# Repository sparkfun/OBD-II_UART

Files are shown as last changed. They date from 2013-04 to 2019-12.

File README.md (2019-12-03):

OBD-II UART
===========

<table class="table table-hover table-striped table-bordered">
  <tr align="center">
   <td><a href="https://cdn.sparkfun.com//assets/parts/3/3/1/4/09555-01a.jpg">OBD-II UART</a></td>
   <td><a href="https://www.sparkfun.com/products/10769">SparkFun Car Diagnostics Kit (RTL-10769)</a></td>
  </tr>
  <tr align="center">
    <td><a href="https://www.sparkfun.com/products/9555">OBD-II UART (WIG-09555)</a></td>
    <td><a href="https://www.sparkfun.com/products/10769">SparkFun Car Diagnostics Kit (RTL-10769)</a></td>
  </tr>
</table>

A board that provides a serial interface using the ELM327 command set with a vehicle's OBD-II bus, and supports all major OBD-II standards. 

Repository Contents
-------------------
* **/Firmware** - Example Arduino sketch
* **/Hardware** - All Eagle design files (.brd, .sch)
* **/Software** - Information about desktop program to use with this board. 

Documentation
--------------
* **[Hookup Guide](https://learn.sparkfun.com/tutorials/obd-ii-uart-hookup-guide)** - Basic hookup guide for the OBD-II UART.
* **[Getting Started with OBD-II](https://learn.sparkfun.com/tutorials/getting-started-with-obd-ii)** - A general guide to the OBD-II protocols used for communication in automotive and industrial applications.

Product Versions
----------------
* [WIG-09555](https://www.sparkfun.com/products/9555) - OBD-II UART board
* [RTL-10769](https://www.sparkfun.com/products/10769) - Car Diagnostics Kit Retail, with OBD-II UART and OBD to DB9 cable.

License Information
-------------------
The hardware is released under [Creative Commons Share-alike 3.0](http://creativecommons.org/licenses/by-sa/3.0/).  
All other code is open source so please feel free to do anything you want with it; you buy me a beer if you use this and we meet someday ([Beerware license](http://en.wikipedia.org/wiki/Beerware)).

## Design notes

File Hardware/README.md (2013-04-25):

# What Are these Files?

The .sch and .brd files hare are Eagle CAD schematic and PCB design files.
These files were created with Eagle 6.4.0, you'll need Eagle 6.0 or later to open them up. There is a free, lite, version of Eagle available from [cadsoftusa.com](cadsoftusa.com).

# License

This product is open source! These Eagle files are released under the Creative Commons Share-Alike Attribution license ([CC BY-SA 3.0](http://creativecommons.org/licenses/by-sa/3.0/us/)).

Please use, reuse, and modify these files as you see fit. Please maintain attribution and release anything derivative under the same license.

- Your friends at SparkFun.

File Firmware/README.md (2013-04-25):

OBD-II UART Example Code
-------------------------

This Arduino sketch is designed to print out OBD data over a [Serial-Enabled LCD](https://www.sparkfun.com/products/9393) from an Arduino.

This sketch is written for Arduino 1.0+.

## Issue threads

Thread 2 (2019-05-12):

Directly communicate with can bus?

DeadlyMelqn, 2019-05-12:
The schematic says it uses the mcp2551 for can bus. Is there a way I can directly communicate with the can-bus without having to go through obd2 interface?

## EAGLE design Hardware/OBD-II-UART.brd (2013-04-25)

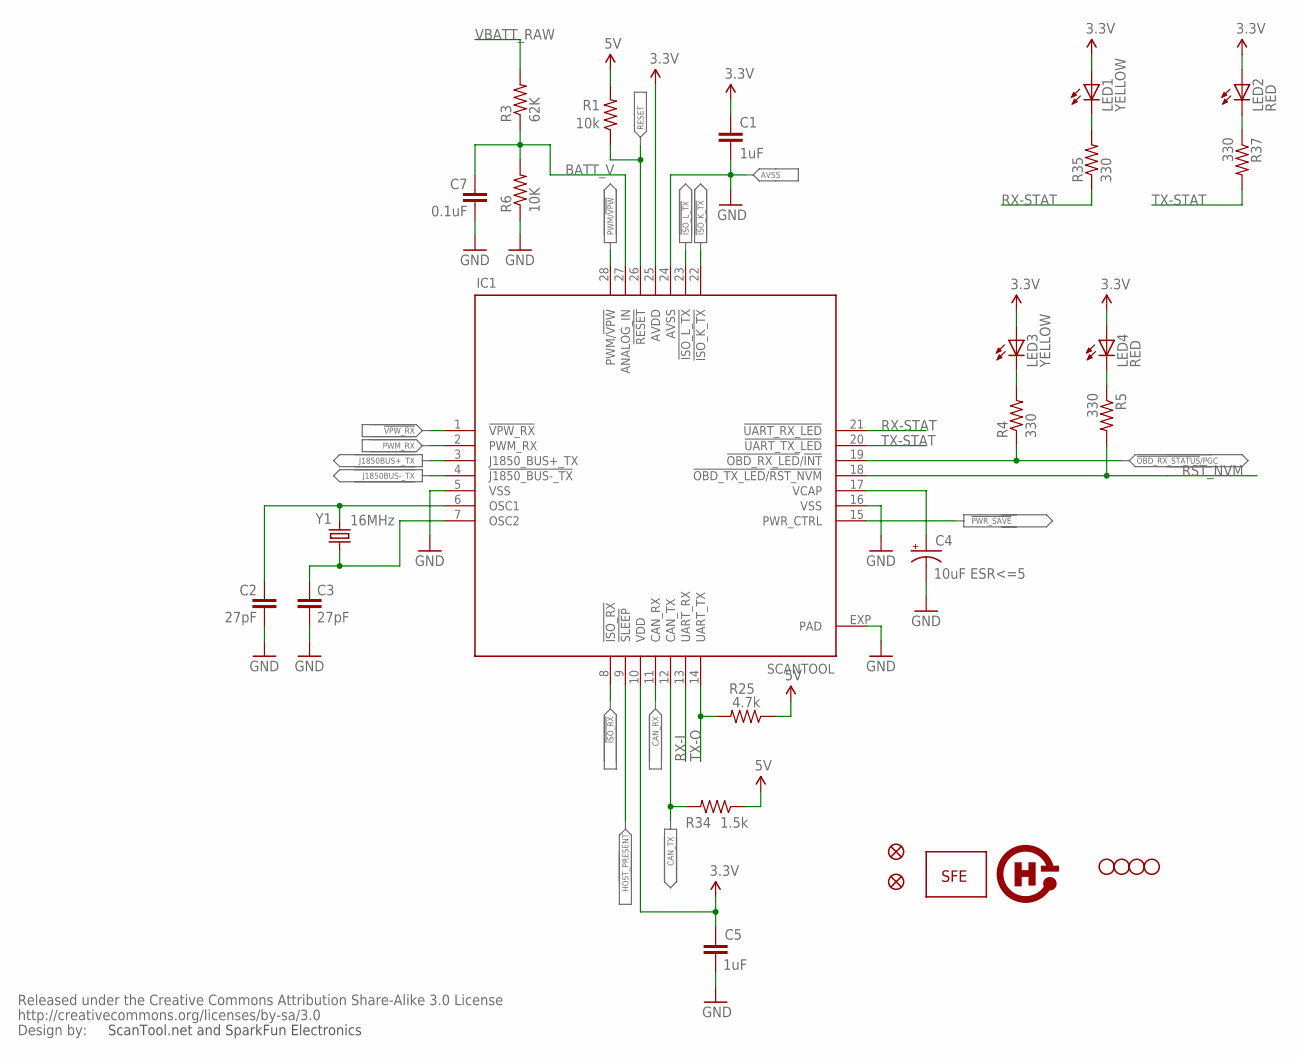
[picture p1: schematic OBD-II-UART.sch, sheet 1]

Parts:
C1, C5: 1uF; 0402-CAP
C2, C3: 27pF; 0402-CAP
C4: 10uF ESR<=5; EIA3216
C7: 0.1uF; 0402-CAP
IC1: SCANTOOL; _STN_SCANTOOL_QFN-28-S
JP2, JP10: FIDUCIAL1X2; FIDUCIAL-1X2
JP3: LOGO-SFENEW; SFE-NEW-WEBLOGO
JP4, JP5, JP6, JP7: STAND-OFF
LED1, LED3: YELLOW; LED-0603
LED2, LED4: RED; LED-0603
R1: 10k; 0402-RES
R3: 62K; 0402-RES
R4, R5, R35, R37: 330; 0402-RES
R6: 10K; 0402-RES
R25: 4.7k; 0402-RES
R34: 1.5k; 0402-RES
U$1: CREATIVE_COMMONS
U$14: OSHW-LOGO
Y1: 16MHz; CRYSTAL-SMD-5X3

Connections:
3.3V: C1.1, C5.1, IC1.10 (VDD), IC1.25 (AVDD), LED1.A, LED2.A, LED3.A, LED4.A; also elsewhere on the board
5V: R1.2, R25.1, R34.1; also elsewhere on the board
!ISO_K_TX: IC1.22 (!ISO_K_TX); also elsewhere on the board
!ISO_L_TX: IC1.23 (!ISO_L_TX); also elsewhere on the board
!ISO_RX: IC1.8 (!ISO_RX); also elsewhere on the board
!OBD_RX_STATUS!/PGC: IC1.19 (!OBD_RX_LED!/!INT), R4.1
!PWR_SAVE: IC1.15 (PWR_CTRL)
!VPW_RX: IC1.1 (!VPW_RX); also elsewhere on the board
BATT_V: C7.1, IC1.27 (ANALOG_IN), R3.1, R6.2
CAN_RX: IC1.11 (CAN_RX); also elsewhere on the board
CAN_TX: IC1.12 (CAN_TX), R34.2; also elsewhere on the board
GND: C1.2, C2.2, C3.2, C4.C (-), C5.2, C7.2, IC1.5 (VSS), IC1.16 (VSS), IC1.24 (AVSS), IC1.EXP (PAD), R6.1; also elsewhere on the board
HOST_PRESENT: IC1.9 (!SLEEP)
J1850BUS+_TX: IC1.3 (J1850_BUS+_TX); also elsewhere on the board
J1850BUS-_TX: IC1.4 (!J1850_BUS-_TX); also elsewhere on the board
unnamed: C4.A (+), IC1.17 (VCAP)
unnamed: LED3.C, R4.2
unnamed: LED4.C, R5.1
unnamed: LED1.C, R35.2
unnamed: LED2.C, R37.1
OSC1: C2.1, IC1.6 (OSC1), Y1.3 (2)
OSC2: C3.1, IC1.7 (OSC2), Y1.1
PWM/!VPW: IC1.28 (PWM/!VPW); also elsewhere on the board
PWM_RX: IC1.2 (PWM_RX); also elsewhere on the board
RESET: IC1.26 (!RESET), R1.1
RST_NVM: IC1.18 (!OBD_TX_LED!/!RST_NVM), R5.2; also elsewhere on the board
RX-I: IC1.13 (UART_RX); also elsewhere on the board
RX-STAT: IC1.21 (!UART_RX_LED), R35.1
TX-O: IC1.14 (UART_TX), R25.2; also elsewhere on the board
TX-STAT: IC1.20 (!UART_TX_LED), R37.2
VBATT_RAW: R3.2; also elsewhere on the board

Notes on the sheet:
AVSS
ScanTool.net and SparkFun Electronics

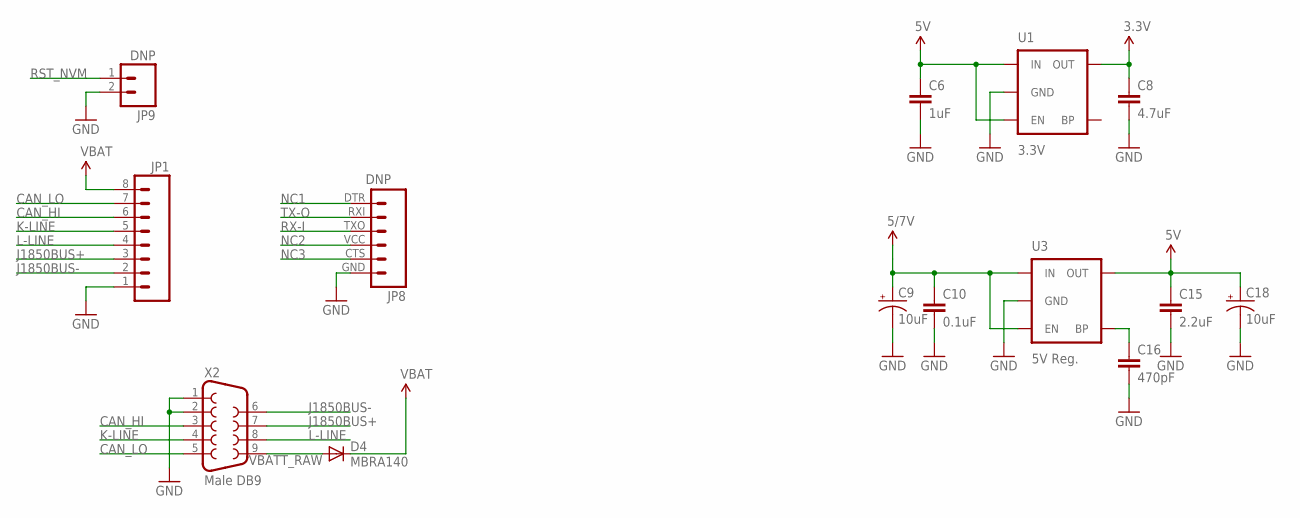
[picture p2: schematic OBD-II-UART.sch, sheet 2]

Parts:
C6: 1uF; 0402-CAP
C8: 4.7uF; 0402-CAP
C9, C18: 10uF; EIA3216
C10: 0.1uF; 0402-CAP
C15: 2.2uF; 0402-CAP
C16: 470pF; 0402-CAP
D4: MBRA140; SMA-DIODE
JP1: M08; 1X08
JP8: DNP; FTDI_BASIC
JP9: DNP; 1X02
U1: 3.3V; SOT23-5
U3: 5V Reg.; SOT23-5
X2: Male DB9; DB9_MALE

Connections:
3.3V: C8.1, U1.5 (OUT); also elsewhere on the board
5V: C6.1, C15.1, C18.A (+), U1.1 (IN), U1.3 (EN), U3.5 (OUT); also elsewhere on the board
CAN_HI: JP1.6, X2.3; also elsewhere on the board
CAN_LO: JP1.7, X2.5; also elsewhere on the board
GND: C6.2, C8.2, C9.C (-), C10.2, C15.2, C16.2, C18.C (-), JP1.1, JP8.GND (6), JP9.2, U1.2 (GND), U3.2 (GND), X2.1, X2.2; also elsewhere on the board
J1850BUS+: JP1.3, X2.7; also elsewhere on the board
J1850BUS-: JP1.2, X2.6; also elsewhere on the board
K-LINE: JP1.5, X2.4; also elsewhere on the board
L-LINE: JP1.4, X2.8; also elsewhere on the board
unnamed: C16.1, U3.4 (BP)
NC1: JP8.DTR (1)
NC2: JP8.VCC (4)
NC3: JP8.CTS (5)
RST_NVM: JP9.1; also elsewhere on the board
RX-I: JP8.TXO (3); also elsewhere on the board
TX-O: JP8.RXI (2); also elsewhere on the board
VBAT: D4.C, JP1.8; also elsewhere on the board
VBATT_RAW: D4.A, X2.9; also elsewhere on the board
VCC: C9.A (+), C10.1, U3.1 (IN), U3.3 (EN); also elsewhere on the board

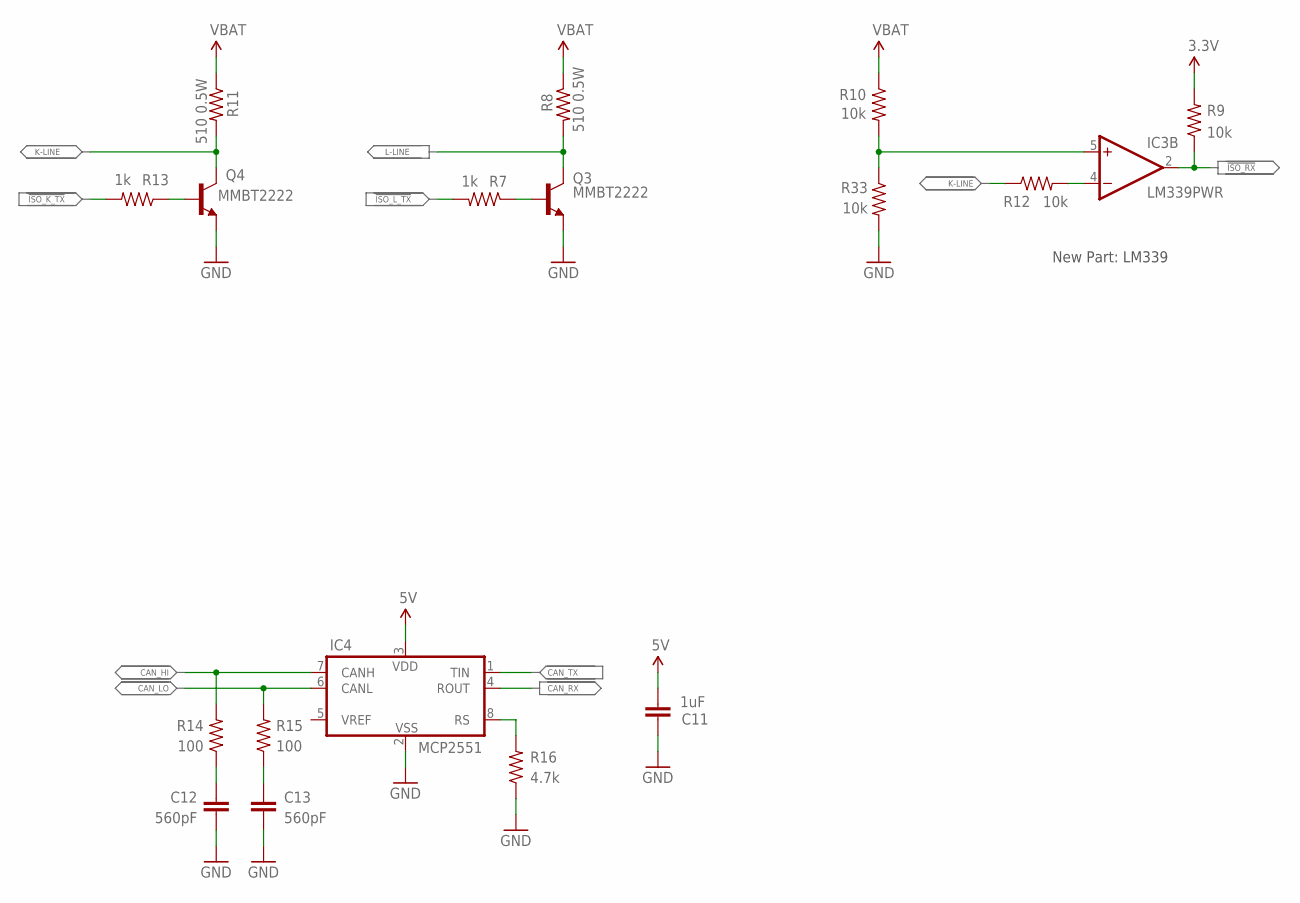
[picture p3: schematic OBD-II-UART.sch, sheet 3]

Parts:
C11: 1uF; 0402-CAP
C12, C13: 560pF; 0402-CAP
IC3: LM339PWR; TSSOP-14
IC4: MCP2551; SO-8
Q3, Q4: MMBT2222; SOT23-3
R7, R13: 1k; 0402-RES
R8, R11: 510 0.5W; 2010
R9, R10, R12, R33: 10k; 0402-RES
R14, R15: 100; 0402-RES
R16: 4.7k; 0402-RES

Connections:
3.3V: R9.2; also elsewhere on the board
5V: C11.1, IC4.3 (VDD); also elsewhere on the board
!ISO_K_TX: R13.2; also elsewhere on the board
!ISO_L_TX: R7.2; also elsewhere on the board
!ISO_RX: IC3.2 (OUT), R9.1; also elsewhere on the board
CAN_HI: IC4.7 (CANH), R14.2; also elsewhere on the board
CAN_LO: IC4.6 (CANL), R15.2; also elsewhere on the board
CAN_RX: IC4.4 (ROUT); also elsewhere on the board
CAN_TX: IC4.1 (TIN); also elsewhere on the board
GND: C11.2, C12.2, C13.2, IC4.2 (VSS), Q3.2 (E), Q4.2 (E), R16.1, R33.2; also elsewhere on the board
K-LINE: Q4.3 (C), R11.2, R12.1; also elsewhere on the board
L-LINE: Q3.3 (C), R8.2; also elsewhere on the board
unnamed: Q4.1 (B), R13.1
unnamed: Q3.1 (B), R7.1
unnamed: IC3.5 (+IN), R10.2, R33.1
unnamed: C12.1, R14.1
unnamed: IC4.8 (RS), R16.2
unnamed: IC3.4 (-IN), R12.2
unnamed: C13.1, R15.1
VBAT: R8.1, R10.1, R11.1; also elsewhere on the board

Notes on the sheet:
New Part: LM339

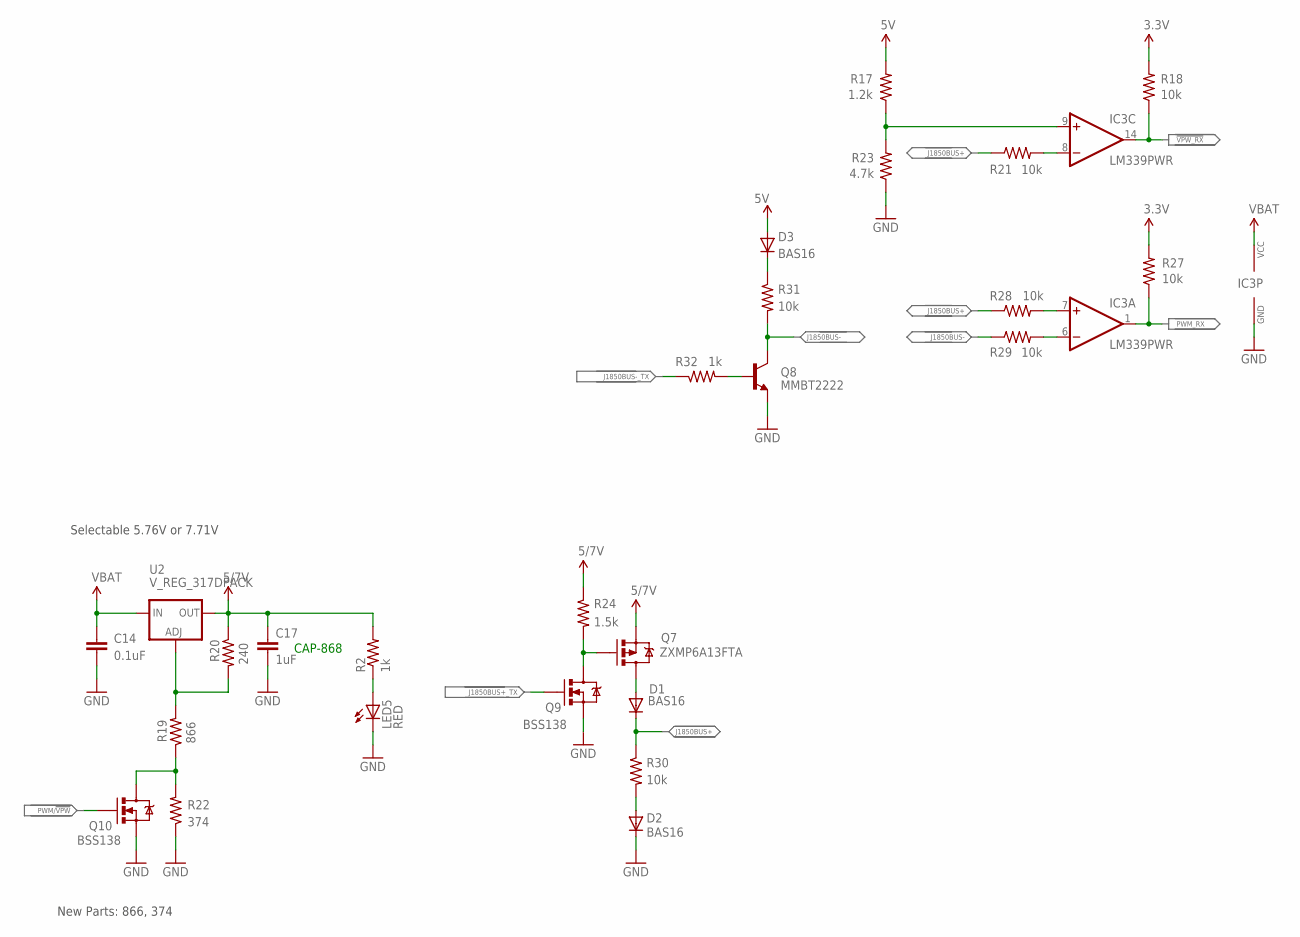
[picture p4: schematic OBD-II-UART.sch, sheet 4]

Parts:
C14: 0.1uF; 0402-CAP
C17: 1uF; 0402-CAP
D1, D2, D3: BAS16; SOD-323
IC3: LM339PWR; TSSOP-14
LED5: RED; LED-0603
Q7: ZXMP6A13FTA; SOT23
Q8: MMBT2222; SOT23-3
Q9, Q10: BSS138; SOT23-3
R2, R32: 1k; 0402-RES
R17: 1.2k; 0402-RES
R18, R21, R27, R28, R29, R30, R31: 10k; 0402-RES
R19: 866; 0402-RES
R20: 240; 0402-RES
R22: 374; 0402-RES
R23: 4.7k; 0402-RES
R24: 1.5k; 0402-RES
U2: V_REG_317DPACK; V-REG_DPACK

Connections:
3.3V: R18.2, R27.2; also elsewhere on the board
5V: D3.2 (A), R17.2; also elsewhere on the board
!VPW_RX: IC3.14 (OUT), R18.1; also elsewhere on the board
GND: C14.2, C17.2, D2.1 (C), IC3.12 (GND), LED5.C, Q8.2 (E), Q9.2 (S), Q10.2 (S), R22.1, R23.1; also elsewhere on the board
J1850BUS+: D1.1 (C), R21.1, R28.1, R30.1; also elsewhere on the board
J1850BUS+_TX: Q9.1 (G); also elsewhere on the board
J1850BUS-: Q8.3 (C), R29.1, R31.2; also elsewhere on the board
J1850BUS-_TX: R32.1; also elsewhere on the board
unnamed: IC3.7 (+IN), R28.2
unnamed: IC3.6 (-IN), R29.2
unnamed: IC3.8 (-IN), R21.2
unnamed: R19.2, R20.2, U2.1 (ADJ)
unnamed: D1.2 (A), Q7.3 (D)
unnamed: IC3.9 (+IN), R17.1, R23.2
unnamed: D3.1 (C), R31.1
unnamed: Q7.1 (G), Q9.3 (D), R24.2
unnamed: Q10.3 (D), R19.1, R22.2
unnamed: D2.2 (A), R30.2
unnamed: Q8.1 (B), R32.2
unnamed: LED5.A, R2.1
PWM/!VPW: Q10.1 (G); also elsewhere on the board
PWM_RX: IC3.1 (OUT), R27.1; also elsewhere on the board
VBAT: C14.1, IC3.3 (VCC), U2.3 (IN); also elsewhere on the board
VCC: C17.1, Q7.2 (S), R2.2, R20.1, R24.1, U2.4 (OUT); also elsewhere on the board

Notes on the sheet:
Selectable 5.76V or 7.71V
New Parts: 866, 374
CAP-868

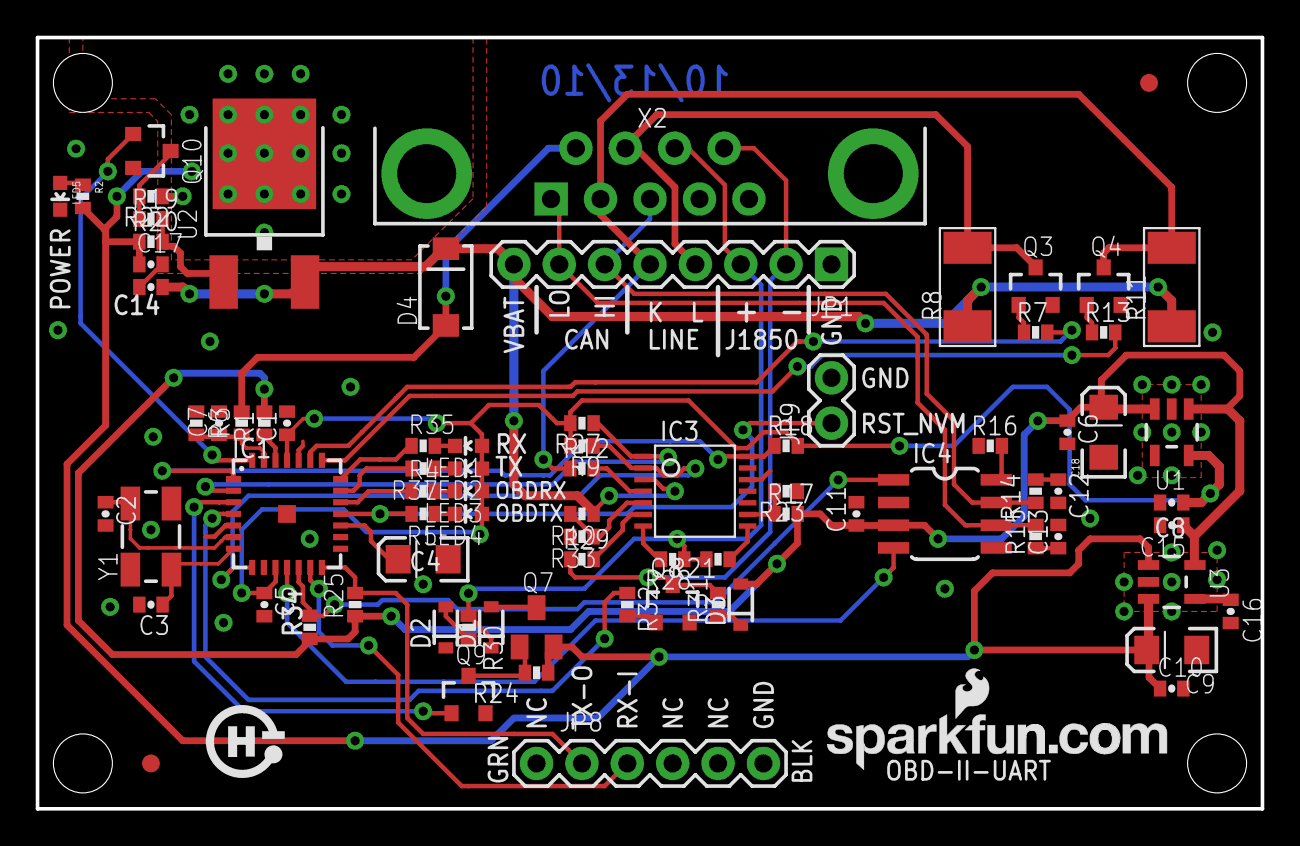
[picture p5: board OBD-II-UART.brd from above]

Board: 2 copper layers, 68.6 x 43.2 mm, 88 parts (0 on the bottom side), 57 nets.

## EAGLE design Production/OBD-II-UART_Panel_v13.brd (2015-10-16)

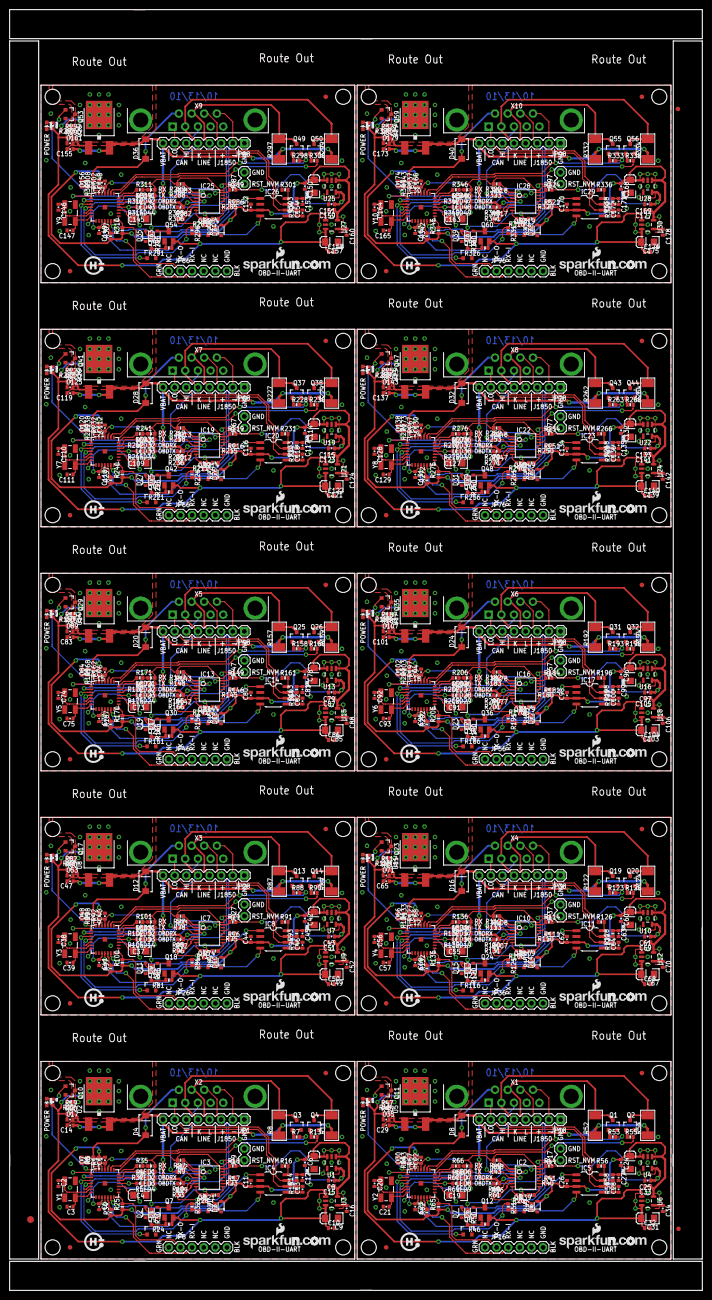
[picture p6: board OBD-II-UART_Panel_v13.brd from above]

Board: 2 copper layers, 151.4 x 279.9 mm, 873 parts (0 on the bottom side), 570 nets.

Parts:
C1, C5, C6, C11, C17, C22, C23, C24, C26, C35, C40, C41, C42, C44, C53, C58, C59, C60, C62, C71, C76, C77, C78, C80, C89, C94, C95, C96, C98, C107, C112, C113, C114, C116, C125, C130, C131, C132, C134, C143, C148, C149, C150, C152, C161, C166, C167, C168, C170, C179: 1uF; 0402-CAP
C2, C3, C20, C21, C38, C39, C56, C57, C74, C75, C92, C93, C110, C111, C128, C129, C146, C147, C164, C165: 27pF; 0402-CAP
C4, C19, C37, C55, C73, C91, C109, C127, C145, C163: 10uF ESR<=5; EIA3216
C7, C10, C14, C29, C30, C32, C47, C48, C50, C65, C66, C68, C83, C84, C86, C101, C102, C104, C119, C120, C122, C137, C138, C140, C155, C156, C158, C173, C174, C176: 0.1uF; 0402-CAP
C8, C25, C43, C61, C79, C97, C115, C133, C151, C169: 4.7uF; 0402-CAP
C9, C18, C31, C36, C49, C54, C67, C72, C85, C90, C103, C108, C121, C126, C139, C144, C157, C162, C175, C180: 10uF; EIA3216
C12, C13, C27, C28, C45, C46, C63, C64, C81, C82, C99, C100, C117, C118, C135, C136, C153, C154, C171, C172: 560pF; 0402-CAP
C15, C33, C51, C69, C87, C105, C123, C141, C159, C177: 2.2uF; 0402-CAP
C16, C34, C52, C70, C88, C106, C124, C142, C160, C178: 470pF; 0402-CAP
D1, D2, D3, D5, D6, D7, D9, D10, D11, D13, D14, D15, D17, D18, D19, D21, D22, D23, D25, D26, D27, D29, D30, D31, D33, D34, D35, D37, D38, D39: BAS16; SOD-323
D4, D8, D12, D16, D20, D24, D28, D32, D36, D40: MBRA140; SMA-DIODE
E$1: FIDUCIAL-1.5X3
E$5, E$8: FIDUCIAL-1X2
IC1, IC6, IC9, IC12, IC15, IC18, IC21, IC24, IC27, IC30: SCANTOOL; _STN_SCANTOOL_QFN-28-S
IC2, IC3, IC7, IC10, IC13, IC16, IC19, IC22, IC25, IC28: LM339PWR; TSSOP-14
IC4, IC5, IC8, IC11, IC14, IC17, IC20, IC23, IC26, IC29: MCP2551; SO-8
JP1, JP18, JP28, JP38, JP48, JP58, JP68, JP78, JP88, JP98: 1X08
JP2, JP10, JP19, JP20, JP29, JP30, JP39, JP40, JP49, JP50, JP59, JP60, JP69, JP70, JP79, JP80, JP89, JP90, JP99, JP100: FIDUCIAL1X2; FIDUCIAL-1X2
JP3, JP11, JP21, JP31, JP41, JP51, JP61, JP71, JP81, JP91: LOGO-SFENEW; SFE-NEW-WEBLOGO
JP4, JP5, JP6, JP7, JP12, JP13, JP14, JP15, JP22, JP23, JP24, JP25, JP32, JP33, JP34, JP35, JP42, JP43, JP44, JP45, JP52, JP53, JP54, JP55, JP62, JP63, JP64, JP65, JP72, JP73, JP74, JP75, JP82, JP83, JP84, JP85, JP92, JP93, JP94, JP95: STAND-OFF
JP8, JP16, JP26, JP36, JP46, JP56, JP66, JP76, JP86, JP96: DNP; FTDI_BASIC
JP9, JP17, JP27, JP37, JP47, JP57, JP67, JP77, JP87, JP97: DNP; 1X02
LED1, LED3, LED6, LED8, LED11, LED13, LED16, LED18, LED21, LED23, LED26, LED28, LED31, LED33, LED36, LED38, LED41, LED43, LED46, LED48: YELLOW; LED-0603
LED2, LED4, LED5, LED7, LED9, LED10, LED12, LED14, LED15, LED17, LED19, LED20, LED22, LED24, LED25, LED27, LED29, LED30, LED32, LED34, LED35, LED37, LED39, LED40, LED42, LED44, LED45, LED47, LED49, LED50: RED; LED-0603
Q1, Q2, Q3, Q4, Q5, Q8, Q13, Q14, Q15, Q19, Q20, Q21, Q25, Q26, Q27, Q31, Q32, Q33, Q37, Q38, Q39, Q43, Q44, Q45, Q49, Q50, Q51, Q55, Q56, Q57: MMBT2222; SOT23-3
Q6, Q9, Q10, Q11, Q16, Q17, Q22, Q23, Q28, Q29, Q34, Q35, Q40, Q41, Q46, Q47, Q52, Q53, Q58, Q59: BSS138; SOT23-3
Q7, Q12, Q18, Q24, Q30, Q36, Q42, Q48, Q54, Q60: ZXMP6A13FTA; SOT23
R1, R9, R10, R12, R18, R21, R26, R27, R28, R29, R30, R31, R33, R36, R38, R39, R42, R43, R44, R49, R50, R57, R60, R61, R71, R72, R73, R74, R77, R78, R79, R84, R85, R92, R95, R96, R106, R107, R108, R109, R112, R113, R114, R119, R120, R127, R130, R131, R141, R142, R143, R144, R147, R148, R149, R154, R155, R162, R165, R166, R176, R177, R178, R179, R182, R183, R184, R189, R190, R197, R200, R201, R211, R212, R213, R214, R217, R218, R219, R224, R225, R232, R235, R236, R246, R247, R248, R249, R252, R253, R254, R259, R260, R267, R270, R271, R281, R282, R283, R284, R287, R288, R289, R294, R295, R302, R305, R306, R316, R317, R318, R319, R322, R323, R324, R329, R330, R337, R340, R341: 10k; 0402-RES
R2, R7, R13, R32, R51, R53, R55, R70, R86, R88, R90, R105, R121, R123, R125, R140, R156, R158, R160, R175, R191, R193, R195, R210, R226, R228, R230, R245, R261, R263, R265, R280, R296, R298, R300, R315, R331, R333, R335, R350: 1k; 0402-RES
R3, R63, R98, R133, R168, R203, R238, R273, R308, R343: 62K; 0402-RES
R4, R5, R35, R37, R66, R67, R68, R69, R101, R102, R103, R104, R136, R137, R138, R139, R171, R172, R173, R174, R206, R207, R208, R209, R241, R242, R243, R244, R276, R277, R278, R279, R311, R312, R313, R314, R346, R347, R348, R349: 330; 0402-RES
R6, R64, R99, R134, R169, R204, R239, R274, R309, R344: 10K; 0402-RES
R8, R11, R52, R54, R87, R89, R122, R124, R157, R159, R192, R194, R227, R229, R262, R264, R297, R299, R332, R334: 510 0.5W; 2010
R14, R15, R58, R59, R93, R94, R128, R129, R163, R164, R198, R199, R233, R234, R268, R269, R303, R304, R338, R339: 100; 0402-RES
R16, R23, R25, R40, R56, R65, R75, R91, R100, R110, R126, R135, R145, R161, R170, R180, R196, R205, R215, R231, R240, R250, R266, R275, R285, R301, R310, R320, R336, R345: 4.7k; 0402-RES
R17, R41, R76, R111, R146, R181, R216, R251, R286, R321: 1.2k; 0402-RES
R19, R47, R82, R117, R152, R187, R222, R257, R292, R327: 866; 0402-RES
R20, R45, R80, R115, R150, R185, R220, R255, R290, R325: 240; 0402-RES
R22, R48, R83, R118, R153, R188, R223, R258, R293, R328: 374; 0402-RES
R24, R34, R46, R62, R81, R97, R116, R132, R151, R167, R186, R202, R221, R237, R256, R272, R291, R307, R326, R342: 1.5k; 0402-RES
U1, U4, U7, U10, U13, U16, U19, U22, U25, U28: 3.3V; SOT23-5
U2, U5, U8, U11, U14, U17, U20, U23, U26, U29: V_REG_317DPACK; V-REG_DPACK
U3, U6, U9, U12, U15, U18, U21, U24, U27, U30: 5V Reg.; SOT23-5
U$1, U$2, U$3, U$4, U$5, U$6, U$7, U$8, U$9, U$14: OSHW-LOGO
X1, X2, X3, X4, X5, X6, X7, X8, X9, X10: Male DB9; DB9_MALE
Y1, Y2, Y3, Y4, Y5, Y6, Y7, Y8, Y9, Y10: 16MHz; CRYSTAL-SMD-5X3

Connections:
3.3V: C1.1, C5.1, C8.1, IC1.10, IC1.25, LED1.A, LED2.A, LED3.A, LED4.A, R9.2, R18.2, R27.2, U1.5
3.3V1: C22.1, C23.1, C25.1, IC6.10, IC6.25, LED6.A, LED7.A, LED8.A, LED9.A, R42.2, R43.2, R44.2, U4.5
3.3V2: C40.1, C41.1, C43.1, IC9.10, IC9.25, LED11.A, LED12.A, LED13.A, LED14.A, R77.2, R78.2, R79.2, U7.5
3.3V3: C58.1, C59.1, C61.1, IC12.10, IC12.25, LED16.A, LED17.A, LED18.A, LED19.A, R112.2, R113.2, R114.2, U10.5
3.3V4: C76.1, C77.1, C79.1, IC15.10, IC15.25, LED21.A, LED22.A, LED23.A, LED24.A, R147.2, R148.2, R149.2, U13.5
3.3V5: C94.1, C95.1, C97.1, IC18.10, IC18.25, LED26.A, LED27.A, LED28.A, LED29.A, R182.2, R183.2, R184.2, U16.5
3.3V6: C112.1, C113.1, C115.1, IC21.10, IC21.25, LED31.A, LED32.A, LED33.A, LED34.A, R217.2, R218.2, R219.2, U19.5
3.3V7: C130.1, C131.1, C133.1, IC24.10, IC24.25, LED36.A, LED37.A, LED38.A, LED39.A, R252.2, R253.2, R254.2, U22.5
3.3V8: C148.1, C149.1, C151.1, IC27.10, IC27.25, LED41.A, LED42.A, LED43.A, LED44.A, R287.2, R288.2, R289.2, U25.5
3.3V9: C166.1, C167.1, C169.1, IC30.10, IC30.25, LED46.A, LED47.A, LED48.A, LED49.A, R322.2, R323.2, R324.2, U28.5
5V: C6.1, C11.1, C15.1, C18.A, D3.2, IC4.3, R1.2, R17.2, R25.1, R34.1, U1.1, U1.3, U3.5
5V1: C24.1, C26.1, C33.1, C36.A, D6.2, IC5.3, R41.2, R57.2, R62.1, R65.1, U4.1, U4.3, U6.5
5V2: C42.1, C44.1, C51.1, C54.A, D10.2, IC8.3, R76.2, R92.2, R97.1, R100.1, U7.1, U7.3, U9.5
5V3: C60.1, C62.1, C69.1, C72.A, D14.2, IC11.3, R111.2, R127.2, R132.1, R135.1, U10.1, U10.3, U12.5
5V4: C78.1, C80.1, C87.1, C90.A, D18.2, IC14.3, R146.2, R162.2, R167.1, R170.1, U13.1, U13.3, U15.5
5V5: C96.1, C98.1, C105.1, C108.A, D22.2, IC17.3, R181.2, R197.2, R202.1, R205.1, U16.1, U16.3, U18.5
5V6: C114.1, C116.1, C123.1, C126.A, D26.2, IC20.3, R216.2, R232.2, R237.1, R240.1, U19.1, U19.3, U21.5
5V7: C132.1, C134.1, C141.1, C144.A, D30.2, IC23.3, R251.2, R267.2, R272.1, R275.1, U22.1, U22.3, U24.5
5V8: C150.1, C152.1, C159.1, C162.A, D34.2, IC26.3, R286.2, R302.2, R307.1, R310.1, U25.1, U25.3, U27.5
5V9: C168.1, C170.1, C177.1, C180.A, D38.2, IC29.3, R321.2, R337.2, R342.1, R345.1, U28.1, U28.3, U30.5
!ISO_K_TX: IC1.22, R13.2
!ISO_K_TX1: IC6.22, R55.2
!ISO_K_TX2: IC9.22, R90.2
!ISO_K_TX3: IC12.22, R125.2
!ISO_K_TX4: IC15.22, R160.2
!ISO_K_TX5: IC18.22, R195.2
!ISO_K_TX6: IC21.22, R230.2
!ISO_K_TX7: IC24.22, R265.2
!ISO_K_TX8: IC27.22, R300.2
!ISO_K_TX9: IC30.22, R335.2
!ISO_L_TX: IC1.23, R7.2
!ISO_L_TX1: IC6.23, R53.2
!ISO_L_TX2: IC9.23, R88.2
!ISO_L_TX3: IC12.23, R123.2
!ISO_L_TX4: IC15.23, R158.2
!ISO_L_TX5: IC18.23, R193.2
!ISO_L_TX6: IC21.23, R228.2
!ISO_L_TX7: IC24.23, R263.2
!ISO_L_TX8: IC27.23, R298.2
!ISO_L_TX9: IC30.23, R333.2
!ISO_RX: IC1.8, IC3.2, R9.1
!ISO_RX1: IC2.2, IC6.8, R43.1
!ISO_RX2: IC7.2, IC9.8, R78.1
!ISO_RX3: IC10.2, IC12.8, R113.1
!ISO_RX4: IC13.2, IC15.8, R148.1
!ISO_RX5: IC16.2, IC18.8, R183.1
!ISO_RX6: IC19.2, IC21.8, R218.1
!ISO_RX7: IC22.2, IC24.8, R253.1
!ISO_RX8: IC25.2, IC27.8, R288.1
!ISO_RX9: IC28.2, IC30.8, R323.1
!OBD_RX_STATUS!/PGC: IC1.19, R4.1
!OBD_RX_STATUS!/PGC1: IC6.19, R68.1
!OBD_RX_STATUS!/PGC2: IC9.19, R103.1
!OBD_RX_STATUS!/PGC3: IC12.19, R138.1
!OBD_RX_STATUS!/PGC4: IC15.19, R173.1
!OBD_RX_STATUS!/PGC5: IC18.19, R208.1
!OBD_RX_STATUS!/PGC6: IC21.19, R243.1
!OBD_RX_STATUS!/PGC7: IC24.19, R278.1
!OBD_RX_STATUS!/PGC8: IC27.19, R313.1
!OBD_RX_STATUS!/PGC9: IC30.19, R348.1
!VPW_RX: IC1.1, IC3.14, R18.1
!VPW_RX1: IC2.14, IC6.1, R44.1
!VPW_RX2: IC7.14, IC9.1, R79.1
!VPW_RX3: IC10.14, IC12.1, R114.1
!VPW_RX4: IC13.14, IC15.1, R149.1
!VPW_RX5: IC16.14, IC18.1, R184.1
!VPW_RX6: IC19.14, IC21.1, R219.1
!VPW_RX7: IC22.14, IC24.1, R254.1
!VPW_RX8: IC25.14, IC27.1, R289.1
!VPW_RX9: IC28.14, IC30.1, R324.1
BATT_V: C7.1, IC1.27, R3.1, R6.2
BATT_V1: C30.1, IC6.27, R63.1, R64.2
BATT_V2: C48.1, IC9.27, R98.1, R99.2
BATT_V3: C66.1, IC12.27, R133.1, R134.2
BATT_V4: C84.1, IC15.27, R168.1, R169.2
BATT_V5: C102.1, IC18.27, R203.1, R204.2
BATT_V6: C120.1, IC21.27, R238.1, R239.2
BATT_V7: C138.1, IC24.27, R273.1, R274.2
BATT_V8: C156.1, IC27.27, R308.1, R309.2
BATT_V9: C174.1, IC30.27, R343.1, R344.2
CAN_HI: IC4.7, JP1.6, R14.2, X2.3
CAN_HI1: IC5.7, JP18.6, R58.2, X1.3
CAN_HI2: IC8.7, JP28.6, R93.2, X3.3
CAN_HI3: IC11.7, JP38.6, R128.2, X4.3
CAN_HI4: IC14.7, JP48.6, R163.2, X5.3
CAN_HI5: IC17.7, JP58.6, R198.2, X6.3
CAN_HI6: IC20.7, JP68.6, R233.2, X7.3
CAN_HI7: IC23.7, JP78.6, R268.2, X8.3
CAN_HI8: IC26.7, JP88.6, R303.2, X9.3
CAN_HI9: IC29.7, JP98.6, R338.2, X10.3
CAN_LO: IC4.6, JP1.7, R15.2, X2.5
CAN_LO1: IC5.6, JP18.7, R59.2, X1.5
CAN_LO2: IC8.6, JP28.7, R94.2, X3.5
CAN_LO3: IC11.6, JP38.7, R129.2, X4.5
CAN_LO4: IC14.6, JP48.7, R164.2, X5.5
CAN_LO5: IC17.6, JP58.7, R199.2, X6.5
CAN_LO6: IC20.6, JP68.7, R234.2, X7.5
CAN_LO7: IC23.6, JP78.7, R269.2, X8.5
CAN_LO8: IC26.6, JP88.7, R304.2, X9.5
CAN_LO9: IC29.6, JP98.7, R339.2, X10.5
CAN_RX: IC1.11, IC4.4
CAN_RX1: IC5.4, IC6.11
CAN_RX2: IC8.4, IC9.11
CAN_RX3: IC11.4, IC12.11
CAN_RX4: IC14.4, IC15.11
CAN_RX5: IC17.4, IC18.11
CAN_RX6: IC20.4, IC21.11
CAN_RX7: IC23.4, IC24.11
CAN_RX8: IC26.4, IC27.11
CAN_RX9: IC29.4, IC30.11
CAN_TX: IC1.12, IC4.1, R34.2
CAN_TX1: IC5.1, IC6.12, R62.2
CAN_TX2: IC8.1, IC9.12, R97.2
CAN_TX3: IC11.1, IC12.12, R132.2
CAN_TX4: IC14.1, IC15.12, R167.2
CAN_TX5: IC17.1, IC18.12, R202.2
CAN_TX6: IC20.1, IC21.12, R237.2
CAN_TX7: IC23.1, IC24.12, R272.2
CAN_TX8: IC26.1, IC27.12, R307.2
CAN_TX9: IC29.1, IC30.12, R342.2
GND: C1.2, C2.2, C3.2, C4.C, C5.2, C6.2, C7.2, C8.2, C9.C, C10.2, C11.2, C12.2, C13.2, C14.2, C15.2, C16.2, C17.2, C18.C, D2.1, IC1.5, IC1.16, IC1.24, IC1.EXP, IC3.12, IC4.2, JP1.1, JP8.GND, JP9.2, LED5.C, Q3.2, Q4.2, Q8.2, Q9.2, Q10.2, R6.1, R16.1, R22.1, R23.1, R33.2, U1.2, U3.2, X2.1, X2.2
GND1: C19.C, C20.2, C21.2, C22.2, C23.2, C24.2, C25.2, C26.2, C27.2, C28.2, C29.2, C30.2, C31.C, C32.2, C33.2, C34.2, C35.2, C36.C, D7.1, IC2.12, IC5.2, IC6.5, IC6.16, IC6.24, IC6.EXP, JP16.GND, JP17.2, JP18.1, LED10.C, Q1.2, Q2.2, Q5.2, Q6.2, Q11.2, R40.1, R48.1, R56.1, R61.2, R64.1, U4.2, U6.2, X1.1, X1.2
GND2: C37.C, C38.2, C39.2, C40.2, C41.2, C42.2, C43.2, C44.2, C45.2, C46.2, C47.2, C48.2, C49.C, C50.2, C51.2, C52.2, C53.2, C54.C, D11.1, IC7.12, IC8.2, IC9.5, IC9.16, IC9.24, IC9.EXP, JP26.GND, JP27.2, JP28.1, LED15.C, Q13.2, Q14.2, Q15.2, Q16.2, Q17.2, R75.1, R83.1, R91.1, R96.2, R99.1, U7.2, U9.2, X3.1, X3.2
GND3: C55.C, C56.2, C57.2, C58.2, C59.2, C60.2, C61.2, C62.2, C63.2, C64.2, C65.2, C66.2, C67.C, C68.2, C69.2, C70.2, C71.2, C72.C, D15.1, IC10.12, IC11.2, IC12.5, IC12.16, IC12.24, IC12.EXP, JP36.GND, JP37.2, JP38.1, LED20.C, Q19.2, Q20.2, Q21.2, Q22.2, Q23.2, R110.1, R118.1, R126.1, R131.2, R134.1, U10.2, U12.2, X4.1, X4.2
GND4: C73.C, C74.2, C75.2, C76.2, C77.2, C78.2, C79.2, C80.2, C81.2, C82.2, C83.2, C84.2, C85.C, C86.2, C87.2, C88.2, C89.2, C90.C, D19.1, IC13.12, IC14.2, IC15.5, IC15.16, IC15.24, IC15.EXP, JP46.GND, JP47.2, JP48.1, LED25.C, Q25.2, Q26.2, Q27.2, Q28.2, Q29.2, R145.1, R153.1, R161.1, R166.2, R169.1, U13.2, U15.2, X5.1, X5.2
GND5: C91.C, C92.2, C93.2, C94.2, C95.2, C96.2, C97.2, C98.2, C99.2, C100.2, C101.2, C102.2, C103.C, C104.2, C105.2, C106.2, C107.2, C108.C, D23.1, IC16.12, IC17.2, IC18.5, IC18.16, IC18.24, IC18.EXP, JP56.GND, JP57.2, JP58.1, LED30.C, Q31.2, Q32.2, Q33.2, Q34.2, Q35.2, R180.1, R188.1, R196.1, R201.2, R204.1, U16.2, U18.2, X6.1, X6.2
GND6: C109.C, C110.2, C111.2, C112.2, C113.2, C114.2, C115.2, C116.2, C117.2, C118.2, C119.2, C120.2, C121.C, C122.2, C123.2, C124.2, C125.2, C126.C, D27.1, IC19.12, IC20.2, IC21.5, IC21.16, IC21.24, IC21.EXP, JP66.GND, JP67.2, JP68.1, LED35.C, Q37.2, Q38.2, Q39.2, Q40.2, Q41.2, R215.1, R223.1, R231.1, R236.2, R239.1, U19.2, U21.2, X7.1, X7.2
GND7: C127.C, C128.2, C129.2, C130.2, C131.2, C132.2, C133.2, C134.2, C135.2, C136.2, C137.2, C138.2, C139.C, C140.2, C141.2, C142.2, C143.2, C144.C, D31.1, IC22.12, IC23.2, IC24.5, IC24.16, IC24.24, IC24.EXP, JP76.GND, JP77.2, JP78.1, LED40.C, Q43.2, Q44.2, Q45.2, Q46.2, Q47.2, R250.1, R258.1, R266.1, R271.2, R274.1, U22.2, U24.2, X8.1, X8.2
GND8: C145.C, C146.2, C147.2, C148.2, C149.2, C150.2, C151.2, C152.2, C153.2, C154.2, C155.2, C156.2, C157.C, C158.2, C159.2, C160.2, C161.2, C162.C, D35.1, IC25.12, IC26.2, IC27.5, IC27.16, IC27.24, IC27.EXP, JP86.GND, JP87.2, JP88.1, LED45.C, Q49.2, Q50.2, Q51.2, Q52.2, Q53.2, R285.1, R293.1, R301.1, R306.2, R309.1, U25.2, U27.2, X9.1, X9.2
GND9: C163.C, C164.2, C165.2, C166.2, C167.2, C168.2, C169.2, C170.2, C171.2, C172.2, C173.2, C174.2, C175.C, C176.2, C177.2, C178.2, C179.2, C180.C, D39.1, IC28.12, IC29.2, IC30.5, IC30.16, IC30.24, IC30.EXP, JP96.GND, JP97.2, JP98.1, LED50.C, Q55.2, Q56.2, Q57.2, Q58.2, Q59.2, R320.1, R328.1, R336.1, R341.2, R344.1, U28.2, U30.2, X10.1, X10.2
J1850BUS+: D1.1, JP1.3, R21.1, R28.1, R30.1, X2.7
J1850BUS+1: D5.1, JP18.3, R26.1, R39.1, R50.1, X1.7
J1850BUS+2: D9.1, JP28.3, R71.1, R74.1, R85.1, X3.7
J1850BUS+3: D13.1, JP38.3, R106.1, R109.1, R120.1, X4.7
J1850BUS+4: D17.1, JP48.3, R141.1, R144.1, R155.1, X5.7
J1850BUS+5: D21.1, JP58.3, R176.1, R179.1, R190.1, X6.7
J1850BUS+6: D25.1, JP68.3, R211.1, R214.1, R225.1, X7.7
J1850BUS+7: D29.1, JP78.3, R246.1, R249.1, R260.1, X8.7
J1850BUS+8: D33.1, JP88.3, R281.1, R284.1, R295.1, X9.7
J1850BUS+9: D37.1, JP98.3, R316.1, R319.1, R330.1, X10.7
J1850BUS+_TX: IC1.3, Q9.1
J1850BUS+_TX1: IC6.3, Q6.1
J1850BUS+_TX2: IC9.3, Q16.1
J1850BUS+_TX3: IC12.3, Q22.1
J1850BUS+_TX4: IC15.3, Q28.1
J1850BUS+_TX5: IC18.3, Q34.1
J1850BUS+_TX6: IC21.3, Q40.1
J1850BUS+_TX7: IC24.3, Q46.1
J1850BUS+_TX8: IC27.3, Q52.1
J1850BUS+_TX9: IC30.3, Q58.1
J1850BUS-: JP1.2, Q8.3, R29.1, R31.2, X2.6
J1850BUS-1: JP18.2, Q5.3, R36.1, R49.2, X1.6
J1850BUS-2: JP28.2, Q15.3, R72.1, R84.2, X3.6
J1850BUS-3: JP38.2, Q21.3, R107.1, R119.2, X4.6
J1850BUS-4: JP48.2, Q27.3, R142.1, R154.2, X5.6
J1850BUS-5: JP58.2, Q33.3, R177.1, R189.2, X6.6
J1850BUS-6: JP68.2, Q39.3, R212.1, R224.2, X7.6
J1850BUS-7: JP78.2, Q45.3, R247.1, R259.2, X8.6
J1850BUS-8: JP88.2, Q51.3, R282.1, R294.2, X9.6
J1850BUS-9: JP98.2, Q57.3, R317.1, R329.2, X10.6
J1850BUS-_TX: IC1.4, R32.1
J1850BUS-_TX1: IC6.4, R51.1
J1850BUS-_TX2: IC9.4, R86.1
J1850BUS-_TX3: IC12.4, R121.1
J1850BUS-_TX4: IC15.4, R156.1
J1850BUS-_TX5: IC18.4, R191.1
J1850BUS-_TX6: IC21.4, R226.1
J1850BUS-_TX7: IC24.4, R261.1
J1850BUS-_TX8: IC27.4, R296.1
J1850BUS-_TX9: IC30.4, R331.1
K-LINE: JP1.5, Q4.3, R11.2, R12.1, X2.4
K-LINE1: JP18.5, Q2.3, R38.1, R54.2, X1.4
K-LINE2: JP28.5, Q14.3, R73.1, R89.2, X3.4
K-LINE3: JP38.5, Q20.3, R108.1, R124.2, X4.4
K-LINE4: JP48.5, Q26.3, R143.1, R159.2, X5.4
K-LINE5: JP58.5, Q32.3, R178.1, R194.2, X6.4
K-LINE6: JP68.5, Q38.3, R213.1, R229.2, X7.4
K-LINE7: JP78.5, Q44.3, R248.1, R264.2, X8.4
K-LINE8: JP88.5, Q50.3, R283.1, R299.2, X9.4
K-LINE9: JP98.5, Q56.3, R318.1, R334.2, X10.4
L-LINE: JP1.4, Q3.3, R8.2, X2.8
L-LINE1: JP18.4, Q1.3, R52.2, X1.8
L-LINE2: JP28.4, Q13.3, R87.2, X3.8
L-LINE3: JP38.4, Q19.3, R122.2, X4.8
L-LINE4: JP48.4, Q25.3, R157.2, X5.8
L-LINE5: JP58.4, Q31.3, R192.2, X6.8
L-LINE6: JP68.4, Q37.3, R227.2, X7.8
L-LINE7: JP78.4, Q43.3, R262.2, X8.8
L-LINE8: JP88.4, Q49.3, R297.2, X9.8
L-LINE9: JP98.4, Q55.3, R332.2, X10.8
unnamed: IC3.7, R28.2
unnamed: C19.A, IC6.17
unnamed: IC3.6, R29.2
unnamed: Q4.1, R13.1
unnamed: Q3.1, R7.1
unnamed: IC3.5, R10.2, R33.1
unnamed: IC3.8, R21.2
unnamed: R19.2, R20.2, U2.1
unnamed: D1.2, Q7.3
unnamed: C12.1, R14.1
unnamed: IC4.8, R16.2
unnamed: IC3.9, R17.1, R23.2
unnamed: IC3.4, R12.2
unnamed: D3.1, R31.1
unnamed: IC2.7, R26.2
unnamed: IC2.6, R36.2
unnamed: IC2.9, R40.2, R41.1
unnamed: Q7.1, Q9.3, R24.2
unnamed: D6.1, R49.1
unnamed: Q6.3, Q12.1, R46.2
unnamed: Q11.3, R47.1, R48.2
unnamed: Q10.3, R19.1, R22.2
unnamed: D7.2, R50.2
unnamed: D2.2, R30.2
unnamed: Q8.1, R32.2
unnamed: C4.A, IC1.17
unnamed: C13.1, R15.1
unnamed: Q5.1, R51.2
unnamed: Q2.1, R55.1
unnamed: LED3.C, R4.2
unnamed: LED4.C, R5.1
unnamed: LED5.A, R2.1
unnamed: Q1.1, R53.1
unnamed: C16.1, U3.4
unnamed: LED1.C, R35.2
unnamed: LED2.C, R37.1
unnamed: IC5.8, R56.2
unnamed: C27.1, R58.1
unnamed: C28.1, R59.1
unnamed: R45.2, R47.2, U5.1
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

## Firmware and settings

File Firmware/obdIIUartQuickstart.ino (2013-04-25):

/*
* OBD-II-UART Quickstart Sketch
* Written by Ryan Owens for SparkFun Electronics 7/5/2011
* Updates for Arduino 1.0+ by Toni Klopfenstein
*
* Released under the 'beerware' license
* (Do what you want with the code, but if we ever meet then you buy me a beer)
*
* This sketch will grab RPM and Vehicle Speed data from a vehicle with an OBD port
* using the OBD-II-UART board from SparkFun electronics. The data will be displayed
* on a serial 16x2 LCD. See the tutorial at https://www.sparkfun.com/tutorials/294
* to learn how to hook up the hardware:
*
*/

#include <SoftwareSerial.h>

//Create an instance of the new soft serial library to control the serial LCD
//Note, digital pin 3 of the Arduino should be connected to Rx of the serial LCD.

SoftwareSerial lcd(2,3);

//This is a character buffer that will store the data from the serial port
char rxData[20];
char rxIndex=0;

//Variables to hold the speed and RPM data.
int vehicleSpeed=0;
int vehicleRPM=0;

void setup(){
  //Both the Serial LCD and the OBD-II-UART use 9600 bps.
  lcd.begin(9600);
  Serial.begin(9600);
  
  //Clear the old data from the LCD.
  lcd.write(254);
  lcd.write(1);  
  
  //Put the speed header on the first row.
  lcd.print("Speed: ");
  lcd.write(254);
  //Put the RPM header on the second row.
  lcd.write(128+64);
  lcd.print("RPM: ");
  
  //Wait for a little while before sending the reset command to the OBD-II-UART
  delay(1500);
  //Reset the OBD-II-UART
  Serial.println("ATZ");
  //Wait for a bit before starting to send commands after the reset.
  delay(2000);
  
  //Delete any data that may be in the serial port before we begin.
  Serial.flush();
}

void loop(){
  //Delete any data that may be in the serial port before we begin.  
  Serial.flush();
  //Set the cursor in the position where we want the speed data.
  lcd.write(254);
  lcd.write(128+8);
  //Clear out the old speed data, and reset the cursor position.
  lcd.print("        ");
  lcd.write(254);
  lcd.write(128+8);
  //Query the OBD-II-UART for the Vehicle Speed
  Serial.println("010D");
  //Get the response from the OBD-II-UART board. We get two responses
  //because the OBD-II-UART echoes the command that is sent.
  //We want the data in the second response.
  getResponse();
  getResponse();
  //Convert the string data to an integer
  vehicleSpeed = strtol(&rxData[6],0,16);
  //Print the speed data to the lcd
  lcd.print(vehicleSpeed);
  lcd.print(" km/h");
  delay(100);
  
  //Delete any data that may be left over in the serial port.
  Serial.flush();
  //Move the serial cursor to the position where we want the RPM data.
  lcd.write(254);
  lcd.write(128 + 69);
  //Clear the old RPM data, and then move the cursor position back.
  lcd.print("          ");
  lcd.write(254);
  lcd.write(128+69);

  //Query the OBD-II-UART for the Vehicle rpm
  Serial.println("010C");
  //Get the response from the OBD-II-UART board
  getResponse();
  getResponse();
  //Convert the string data to an integer
  //NOTE: RPM data is two bytes long, and delivered in 1/4 RPM from the OBD-II-UART
  vehicleRPM = ((strtol(&rxData[6],0,16)*256)+strtol(&rxData[9],0,16))/4;
  //Print the rpm data to the lcd
  lcd.print(vehicleRPM); 
  
  //Give the OBD bus a rest
  delay(100);
  
}

//The getResponse function collects incoming data from the UART into the rxData buffer
// and only exits when a carriage return character is seen. Once the carriage return
// string is detected, the rxData buffer is null terminated (so we can treat it as a string)
// and the rxData index is reset to 0 so that the next string can be copied.
void getResponse(void){
  char inChar=0;
  //Keep reading characters until we get a carriage return
  while(inChar != '\r'){
    //If a character comes in on the serial port, we need to act on it.
    if(Serial.available() > 0){
      //Start by checking if we've received the end of message character ('\r').
      if(Serial.peek() == '\r'){
        //Clear the Serial buffer
        inChar=Serial.read();
        //Put the end of string character on our data string
        rxData[rxIndex]='\0';
        //Reset the buffer index so that the next character goes back at the beginning of the string.
        rxIndex=0;
      }
      //If we didn't get the end of message character, just add the new character to the string.
      else{
        //Get the new character from the Serial port.
        inChar = Serial.read();
        //Add the new character to the string, and increment the index variable.
        rxData[rxIndex++]=inChar;
      }
    }
  }
}

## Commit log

2013-04-25 Actually adding files in this commit.
    [OBD-II-UART.brd, OBD-II-UART.sch]
2015-10-16 new v13 panel
    [OBD-II-UART_Panel_v13.brd]

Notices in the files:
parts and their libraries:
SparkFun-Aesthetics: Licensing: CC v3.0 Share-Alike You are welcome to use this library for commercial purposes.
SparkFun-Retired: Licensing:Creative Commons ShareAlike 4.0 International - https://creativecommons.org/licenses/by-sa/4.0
